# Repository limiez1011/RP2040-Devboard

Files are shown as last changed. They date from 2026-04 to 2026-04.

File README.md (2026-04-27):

# RP2040-Devboard
Basic devboard with rp2040 MCU and 2.54mm headers.




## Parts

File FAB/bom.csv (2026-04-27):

Designator | Footprint | Quantity | Value | LCSC Part #
C1, C2 | 603 | 2 | 1uF | C15849
C10, C11, C13, C14, C17, C4, C5, C6, C7, C8, C9 | 402 | 11 | 100nF | C1525
C12, C3 | 402 | 2 | 1uF | C52923
C15, C16 | 402 | 2 | 15pF | C86285
J1 | USB_C_Receptacle_HRO_TYPE-C-31-M-12 | 1 | USB_C_Receptacle_USB2.0_14P | C165948
R1, R2 | 402 | 2 | 27 | C25100
R3, R4 | 402 | 2 | 5.1K | C25905
R5 | 402 | 1 | 10K | C25744
R6 | 402 | 1 | 1K | C11702
SW1 | SW_TS-1088-AR02016 | 1 | SW_Push | C720477
U1 | QFN-56-1EP_7x7mm_P0.4mm_EP3.2x3.2mm | 1 | RP2040 | C2040
U2 | SOT94P279X129-5N | 1 | RT9013-33GB | C47773
U3 | Winbond_USON-8-1EP_3x2mm_P0.5mm_EP0.2x1.6mm | 1 | W25Q128JVSIQ | C2986331
Y1 | XTAL_ABM8G-12.000MHZ-4Y-T3 | 1 | ABM8G-12.000MHZ-4Y-T3 | C70565

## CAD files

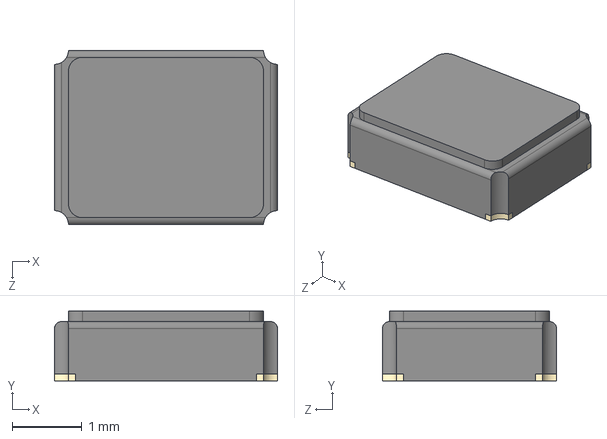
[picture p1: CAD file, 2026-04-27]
Kicad/Footprints & Symbols/ABM8G-12.000MHZ-4Y-T3/ABM8G-12.000MHZ-4Y-T3.step
3.20 x 1.00 x 2.50 mm

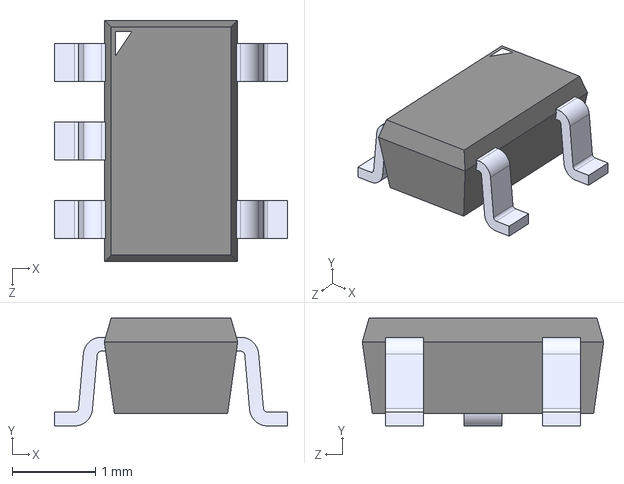
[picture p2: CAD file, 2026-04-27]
Kicad/Footprints & Symbols/RT9013-33GB/RT9013-33GB.step
2.79 x 1.30 x 2.90 mm

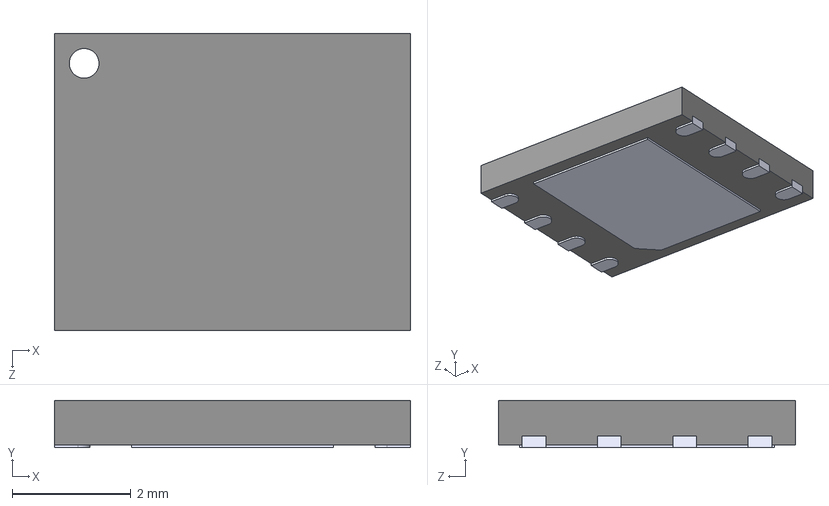
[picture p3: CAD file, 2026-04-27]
Kicad/Footprints & Symbols/SON127P500X600X80-9N/SON127P500X600X80-9N.step
6.00 x 0.8 x 5.00 mm

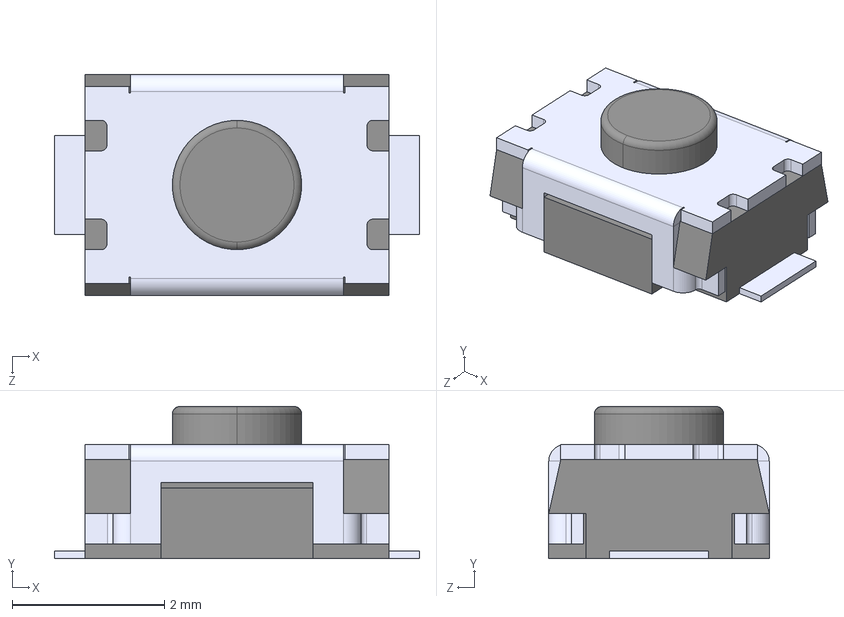
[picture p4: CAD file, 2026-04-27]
Kicad/Footprints & Symbols/TS-1088-AR02016/TS-1088-AR02016.step
4.80 x 2.00 x 2.90 mm

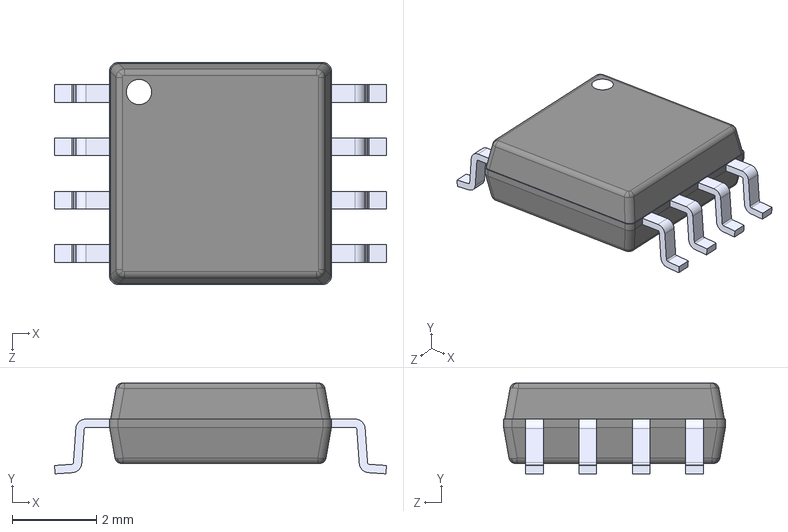
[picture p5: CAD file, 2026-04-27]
Kicad/Footprints & Symbols/W25Q128JVSIQ/W25Q128JVSIQ.step
7.90 x 2.16 x 5.28 mm

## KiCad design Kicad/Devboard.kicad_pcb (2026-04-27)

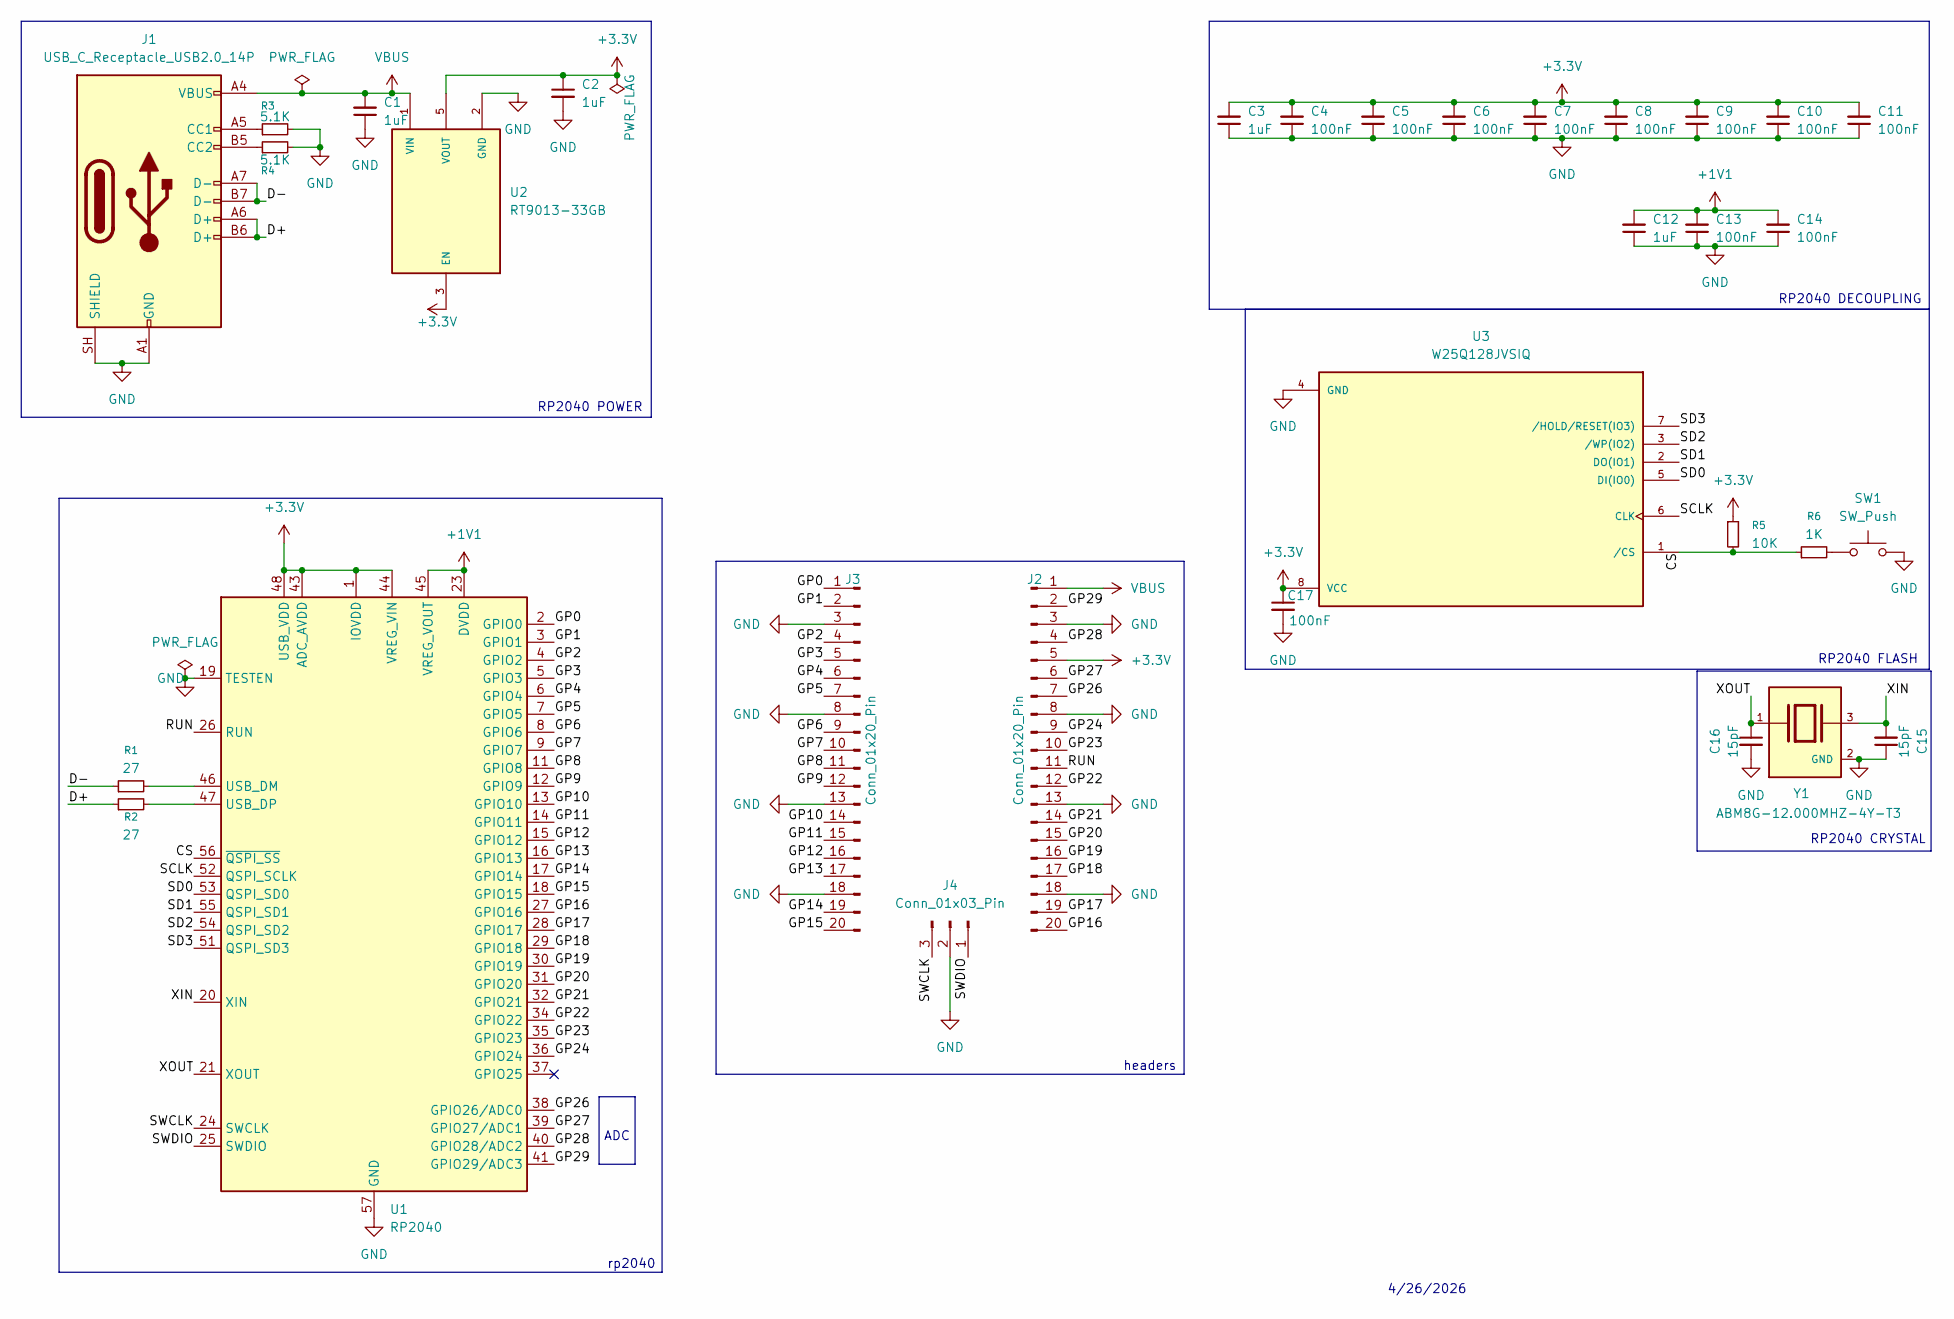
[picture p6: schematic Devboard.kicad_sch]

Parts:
C1, C2: 1uF; C_0603_1608Metric
C3, C12: 1uF; C_0402_1005Metric
C4, C5, C6, C7, C8, C9, C10, C11, C13, C14, C17: 100nF; C_0402_1005Metric
C15, C16: 15pF; C_0402_1005Metric
J1: USB_C_Receptacle_USB2.0_14P; USB_C_Receptacle_HRO_TYPE-C-31-M-12
J2, J3: Conn_01x20_Pin; PinHeader_1x20_P2.54mm_Vertical
J4: Conn_01x03_Pin; PinHeader_1x03_P2.54mm_Vertical
R1, R2: 27; R_0402_1005Metric
R3, R4: 5.1K; R_0402_1005Metric
R5: 10K; R_0402_1005Metric
R6: 1K; R_0402_1005Metric
SW1: SW_Push; SW_TS-1088-AR02016
U1: RP2040; QFN-56-1EP_7x7mm_P0.4mm_EP3.2x3.2mm
U2: RT9013-33GB; SOT94P279X129-5N; PARTREV Aprill 2011
U3: W25Q128JVSIQ; Winbond_USON-8-1EP_3x2mm_P0.5mm_EP0.2x1.6mm; PARTREV I
Y1: ABM8G-12.000MHZ-4Y-T3; XTAL_ABM8G-12.000MHZ-4Y-T3; PARTREV 08.13.15

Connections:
+1V1: C12.2, C13.2, C14.2, U1.23 (DVDD), U1.45 (VREG_VOUT), U1.50 (DVDD)
+3.3V: C2.1, C3.2, C4.2, C5.2, C6.2, C7.2, C8.2, C9.2, C10.2, C11.2, C17.1, J2.5, R5.1, U1.1 (IOVDD), U1.10 (IOVDD), U1.22 (IOVDD), U1.33 (IOVDD), U1.42 (IOVDD), U1.43 (ADC_AVDD), U1.44 (VREG_VIN), U1.48 (USB_VDD), U1.49 (IOVDD), U2.3 (EN), U2.5 (VOUT), U3.8 (VCC)
/CS: R5.2, R6.1, U1.56 (~QSPI_SS), U3.1 (/CS)
/D+: J1.A6 (D+), J1.B6 (D+), R2.1
/D-: J1.A7 (D-), J1.B7 (D-), R1.1
/GP0: J3.1, U1.2 (GPIO0)
/GP1: J3.2, U1.3 (GPIO1)
/GP2: J3.4, U1.4 (GPIO2)
/GP3: J3.5, U1.5 (GPIO3)
/GP4: J3.6, U1.6 (GPIO4)
/GP5: J3.7, U1.7 (GPIO5)
/GP6: J3.9, U1.8 (GPIO6)
/GP7: J3.10, U1.9 (GPIO7)
/GP8: J3.11, U1.11 (GPIO8)
/GP9: J3.12, U1.12 (GPIO9)
/GP10: J3.14, U1.13 (GPIO10)
/GP11: J3.15, U1.14 (GPIO11)
/GP12: J3.16, U1.15 (GPIO12)
/GP13: J3.17, U1.16 (GPIO13)
/GP14: J3.19, U1.17 (GPIO14)
/GP15: J3.20, U1.18 (GPIO15)
/GP16: J2.20, U1.27 (GPIO16)
/GP17: J2.19, U1.28 (GPIO17)
/GP18: J2.17, U1.29 (GPIO18)
/GP19: J2.16, U1.30 (GPIO19)
/GP20: J2.15, U1.31 (GPIO20)
/GP21: J2.14, U1.32 (GPIO21)
/GP22: J2.12, U1.34 (GPIO22)
/GP23: J2.10, U1.35 (GPIO23)
/GP24: J2.9, U1.36 (GPIO24)
/GP26: J2.7, U1.38 (GPIO26/ADC0)
/GP27: J2.6, U1.39 (GPIO27/ADC1)
/GP28: J2.4, U1.40 (GPIO28/ADC2)
/GP29: J2.2, U1.41 (GPIO29/ADC3)
/RUN: J2.11, U1.26 (RUN)
/SCLK: U1.52 (QSPI_SCLK), U3.6 (CLK)
/SD0: U1.53 (QSPI_SD0), U3.5 (DI(IO0))
/SD1: U1.55 (QSPI_SD1), U3.2 (DO(IO1))
/SD2: U1.54 (QSPI_SD2), U3.3 (/WP(IO2))
/SD3: U1.51 (QSPI_SD3), U3.7 (/HOLD/RESET(IO3))
/SWCLK: J4.3, U1.24 (SWCLK)
/SWDIO: J4.1, U1.25 (SWDIO)
/XIN: C15.2, U1.20 (XIN), Y1.3
/XOUT: C16.1, U1.21 (XOUT), Y1.1
GND: C1.1, C2.2, C3.1, C4.1, C5.1, C6.1, C7.1, C8.1, C9.1, C10.1, C11.1, C12.1, C13.1, C14.1, C15.1, C16.2, C17.2, J1.A1 (GND), J1.A12 (GND), J1.B1 (GND), J1.B12 (GND), J1.SH (SHIELD), J2.3, J2.8, J2.13, J2.18, J3.3, J3.8, J3.13, J3.18, J4.2, R3.2, R4.2, SW1.2, U1.19 (TESTEN), U1.57 (GND), U2.2 (GND), U3.4 (GND), U3.9, Y1.2 (GND), Y1.4 (GND)
unnamed: J1.A5 (CC1), R3.1
unnamed: J1.B5 (CC2), R4.1
unnamed: R6.2, SW1.1
unnamed: R1.2, U1.46 (USB_DM)
unnamed: R2.2, U1.47 (USB_DP)
VBUS: C1.2, J1.A4 (VBUS), J1.A9 (VBUS), J1.B4 (VBUS), J1.B9 (VBUS), J2.1, U2.1 (VIN)

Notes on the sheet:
RP2040 POWER
rp2040
RP2040 CRYSTAL
ADC
headers
RP2040 DECOUPLING
4/26/2026
RP2040 FLASH

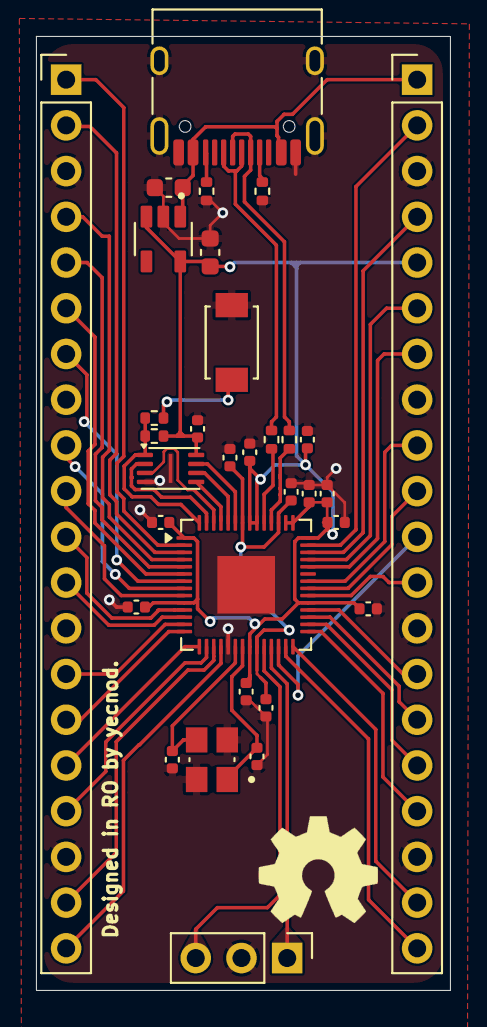
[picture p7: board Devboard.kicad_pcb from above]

Board: 2 copper layers, 23.0 x 53.0 mm, 32 parts (0 on the bottom side), 51 nets.
